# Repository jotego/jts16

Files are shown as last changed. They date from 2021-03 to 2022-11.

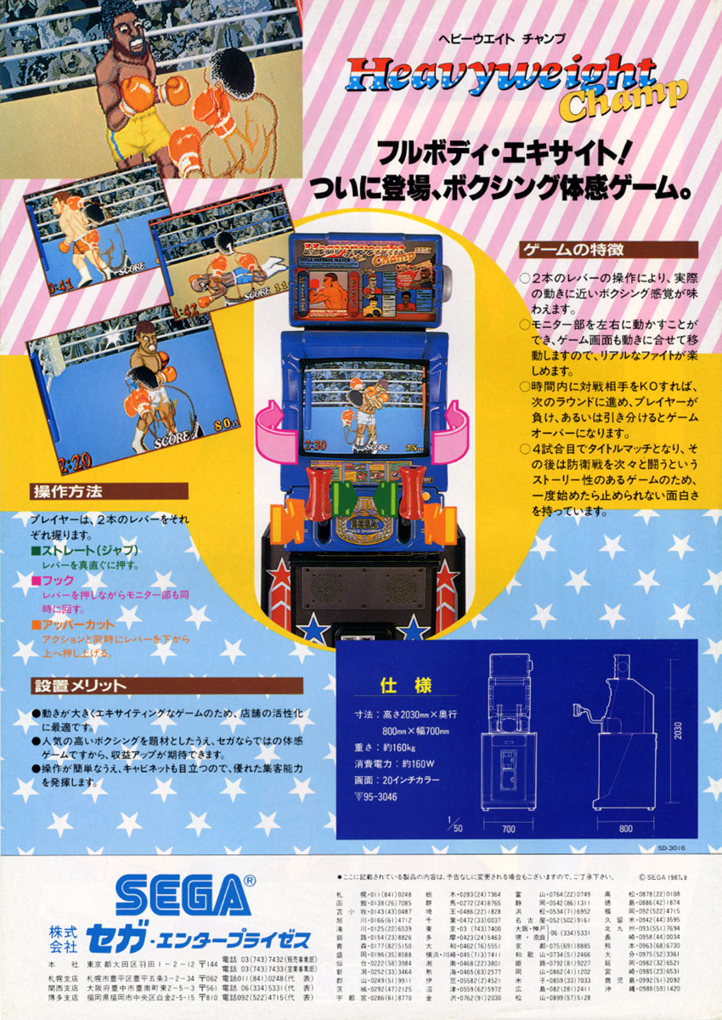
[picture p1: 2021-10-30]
doc/hwchamp controls.jpg

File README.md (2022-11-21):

# JTS16

You can show your appreciation through
* Patreon: https://patreon.com/jotego
* Paypal: https://paypal.me/topapate
* Github: https://github.com/sponsors/jotego

SEGA System 16 compatible verilog core for FPGA by Jose Tejada (jotego). This core was developed with the help of a SEGA System 16B model 171-5358 board lent by FunkyCochise and the Out Run board donated by Travis Brown.

This project aims to be compatible with System 16, Out Run and derivatives.

# Supported Games

Most games work correctly. Some games have problems mapping their inputs because the original arcade was not a joystick with buttons but something else hard to translate. Please check the [issues section in Github](https://github.com/jotego/jts16/issues).

Developer's note: encrypted games don't work if the core is compiled using the J68 CPU module for M68000.

# Special Inputs

Game           |  Players |  Analog    | Other
---------------|----------|------------|---------------
Passing Shot   |    4     |            |
SDI            |    1     |  2 axis    | trackball
Sukeban        |    1     |            | Keyboard-like
Major League   |    1     |  3 axis    |
Dump Matsumoto |    1     |            | inputs via 8751
Ace Attack     |    1     |            | inputs via CXD1095
Out Run        |    1     |  2 axis    |

# Core Division

Because of the hardware variety, there are different cores targeted for each of them

System               |  Core    | Logic Usage | BRAM Usage
---------------------|----------|-------------|-------------
16A                  | jts16    | 22,149      | 374,458
16B i8751            | jts16b   | 23,073      | 364,218
Super Hang-On        | jtshanon |             |
Out Run              | jtoutrun | 22,719      | 441,238

MiST has 608,256 memory bits and 24,624 logic elements.
Although the MCU can be synthesized in MiST and SiDi, timings are usually broken and requires several runs with different seeds because the FPGA is almost full. For MiSTer it seems to always go well.

The original Out Run design used a frame buffer to draw the sprites. The frame buffer is maintained for Pocket and MiSTer but it is not supported on some FPGA systems, like MiST. Because of the large number of sprites, it is not possible to process all sprite data in one scan line, so MiST and other systems some times have garbled lines as a result. This problem is minimized by doubling the video clock in those systems (up to 100MHz) but it still is visible in some scenes. Another side effect of missing the frame buffer is that sprites appear one-frame ahead of time in those systems.

Because of lack of sufficient internal FPGA RAM (called BRAM), MiST and other smaller systems cannot run the encrypted versions of these games.

Despite these problems, the MiST version is fully playable.

# PCB Check List

These items need double checking on the PCB

* How much shadow is created by sprite palette 3F? The core assumes 25% attenuation

# Clocks

HSync (OSSC) 15.73kHz
VSync (Analog Discovery) 60.042Hz
Vblank: 2.427 ms (38 lines)

Crystal Oscillators (System 16B)

Location | Freq (MHz) | Use
---------|------------|-------
B1       | 20         | M68k
E12      | 8.000      | Sound
G1       | 25.1748    | Video

Pixel clock: 6.2937 MHz

Estimated geometry:
    400 pixels/line = 63.555us = 15.734 kHz
    262 lines/frame

Core clock: 50.3496 MHz

Dividers:

Clock   |  m   |  n
--------|------|-----
25.1748 |   1  |   2
20      |  29  |  73
8       | 109  | 686

# 8255 Connections

Line   |  Destination
-------|--------------
PA     |  Sound latch
PB3-0  |  Coin lock ?
PB4    |  Display enable
PB6-5  |  ?
PB7    |  Flip (pull down)
PC7    |  Port A handshaking signal /OBF -> Sound /NMI
PC6    |  Port A handshaking signal ACK
PC5-3  |  Unconnected
PC2    |  To PAL 315-5107 pin 9 (SCONT1)
PC1    |  To PAL 315-5108 pin 19 (SCONT0)
PC0    |  To MUTE input on MB3733 amplifier (0=sound disabled)

# Memory Size

Item      |  Size (kB)
----------|------------
Main ROM  |  512
Main RAM  |   16
Object    |    2
Palette   |    4
Char      |    4
Scroll    |   32 (?)

# Support

You can show your appreciation through
* Patreon: https://patreon.com/jotego
* Paypal: https://paypal.me/topapate

# Licensing

Contact the author for special licensing needs. Otherwise follow the GPLv3 license attached.

# Patron Acknowledgement

Apart from the directors and supported shown in the core credits screen,
the following patrons also supported the development of JTS16:

```
0x157fae8              3style                 8bits4ever             Aaron Ray
Adam Leslie            Adam Rykowski          Adam Small             Adrian Labastida
Alan Shurvinton        Alda Alesio            Alec Peden             Alex Baldwin
Alex Mandic            Alexander Facchini     Alexander Lash         Alexander Upton
Alfonso Clemente       Allen Tipper           Allen Tulowitzki       Allister Fiend
Alvaro Paniagua        Andrea Chiavazza       Andreas Micklei        Andrew Boudreau
Andrew Hannan          Andrew P Gibson        Andrew Schmidt         Angel Aguinaga
Angelfred              Angelo Kanaris         AnotherJoe             Anselmo Moreno
Anthony Cheng          Anthony Monaco         Anton Gale             Arend Pronk
Arkadiusz              Arthur Fung            Aurich Lawson          BRCDEvg
Banane                 Barley Cheezers        Bear S                 Ben Cullen
Ben Tiefert            Ben Toman              BigRedPimp             Bit2018
Bitmap Bureau          Bitmaps Retro          Bliz 452               Boris Pruessmann
Brandon Lennie         Brandon Peach          Brandon Thomas         Brandoon
Brent Fraser           Brian Peek             Brian Shiver           Brianna Cluck
Bruce Fontaine         Bruno Meyere           Bruno Silva            Bryan Evans
Byshop303              Cameron Berkenpas      Cameron Tinker         Carlos Bailleres
Carlos Gruberman       Casey Hamann           Cedric Vioget          Cesar Sandoval
Chad Page              Charles                Chris                  Chris Angelini
Chris Babishoff        Chris D                Chris Davis            Chris Hauk
Chris Hoff             Chris Maguire          Chris Mzhickteno       Chris O'Neil
Chris Petroni          Chris Scully           Chris Sewell           Chris Tuckwell
Chris W Miller         Chris keesler          Chris smith            Christophe GARDES
Clayton Anderson       Clinton Cronin         Cobra Clips            Colin Colehour
Cory Sizemore          Cory Stargel           Cosmic Savant          Damien D
Daniel                 Daniel .               Daniel Dongil          Daniel Fowler
Daniel Page            Daniele Pellegrini     Danny Garfield         Darren Attwood
Darren Wootton         Daryll David           Dasutin                Dave Bennett
Dave Douglas           Dave Nice              David                  David Drury
David Fleetwood        David Jones            David Stone            Denis Brækhus
Dennis Ranker          Denny Letourneau       Devon Meunier          Diana Carolina
Didier Touron          Dimitris Zongas        Douglas Alves          Dr Catjail
Dr. Octagon            DrMnike                Dre137                 Dubesinhower
Ed                     Edward Mallett         Enthropy               Epixjava
Eren Kotan             Eric                   Eric Gutt              Eric J Faulkes
Eric Schneider         Eric Sorensen          F34R                   FROELIGER
Fabio Michelin         Fabrice Odero          Fabricio               Federico
Five Year Guy          Flavio Real            Florian Raoult         Franco Catrin
Fred Rojas             Gareth Jones           Gavin C                GeorgeSpinner
GigaBoots              Girth305               Glenn Percival         Gord Allott
Grant McNaught         Greg Sargent           Gregory Val            Grummkol
Guillermo Tunon        Gutxi Haitz            Guy Taylor             Gwaland
HamsoloPlays           Harmonica              Henry                  Henry R
Hentai Joe             Hugo Pinto             ItalianGrandma         ItsBobDudes
JR                     JSwan                  Jack Sammons           Jacob Hoffman
Jacob Lawter           Jakob Schmid           James Dingo            James Durden
James Mann             James Nivin            James Trautner         James Wilson
Janne Heikkarainen     Jason Baker            Javier Heredia         Jayson Larose
Jeremy Hopkins         Jerry Langwell         Jerry Suggs            Jerry Yuan
Jesse Clark            Jesse Rankin           Jim Knowler            Jimmy Richards
Jockel                 Joe Dinges             Joe Giuliano           Joel Albino
John Figueroa          John Fletcher          John Silva             John T. Keen
John Torn              John Wilson            John Woods             Johnny harvick
Jonah Phillips         Jonathan               Jonathan Tuttle        JonathanValls
Joost Peters           Jork Sonkinfield       Jose Perez             Josep Barbie
Joseph Kulinski        Joseph Milazzo         Joseph Mogavero        Josh Hogan
Josh Mayer             Josh Yates-Walker      Juan Barriga           Juan Pablo
Justin D'Arcangelo     Kai Cherry             Kai Luotojoki          Kaiosten
Kaya Bear              Keith Gordon           Kellerkind             Ken B
Ken Scott              Kevin Dayton           Kike Alcor             Kimberley Fisher
KnC                    Konrad                 Kricys                 Kristian.
KrzysFR                Kyle Pedersen          L.Rapter               Lakeside
Lee Grocott            Lee Osborne            Lucian                 Lucius Bono
Luis F Giron           M Reznor               MaDDoG                 Mack H
Madox                  Magnus Kvevlander      Mane Function          Manksalot
Manuel Astudillo       Marc Nuernberger       Marcello Medini        Mark Floyd
Mark Saunders          MarthSR                Matt Bouverie          Matt Evans
Matt Hargett           Matt Heinrich          Matt McCarthy          Matt Postema
Matt Simonds           Matt Vulcano           Matthew Compston       Matthew Woodford
Matthieu Marchione     Max                    Max Power              MechaGG
MiSTer Retro           Michael Anderson       Michael Bariszlovits   Michael Martin
Michael Rea            Michael_DKT            Mickaël Renou          Mike Holzinger
Mike Jegenjan          Mottzilla              Mysterious Benefactor  Nadir Shabazz
Nailbomb               Nando Iron             Nathan Souris          NerdyNester
Nicholas Bold          Nick Daniels           Nick Delia             Nick Gudauskas
Nico Stamp             Niko                   NonstopXiaowei         Noyman29
Obvious Fakename       Omar                   Omar Najera            OopsAllBerrys
Oriez                  Oskar Maria            Oskar Sigvardsson      Oyvind Christiansen
Pablo Avila-Estevez    Patrick McCarron       Patrick Roman          Paul
Paul Cunningham        Paulo M.               Paulo Nascimento       Paweł Mandes
PeFClic                Pedro Santiago         Per Ole                Peter Mehes
Philip Lai             Philip Lawson          Pierre-Emmanuel Martin Potato
ProfessorAnon          R Omar Leal            Rachel Schaeffer       Ralph Barbagallo
Ramon Gamaliel         RandomRetro            Raphael Melgar         Raul3D
RayGun                 RetroRGB               Retro_Brewz            Rex Kung
Rex Willer             Richard Eng            Richard Murillo        Richard Simpson
Robert Hayes           Robin Hertzberg        Romain Dijoux          Romier Silvera
Ronald Dean            Ronan Amicel           RoryDropkick           Ruben
Rune P                 Russ Crandall          Ryan                   Ryan Clark
Ryne Weiss             SIDKidd64              Saiyan                 Sam Hall
Samuel Pizarro         Samuel Warner          Sang Hee               Sascha Zupanek
Schnookums             Scott Bender           Ser Erris              Seth Wickline
Shad Uttam             Shannon King           Shen mue               Sherwood Hachtman
Sigmund68k             Skeletex               Spank Minister         Stadium ARTs
SteelRush              Stefan Krueger         Stephen                Stephen Pagenstecher
Stephen R Price        Steve Lin              Steve Skrzyniarz       Steve Tack
Steven A               Steven Hansen          Stoneman               Stuart Morton
Sunder Raj             SuperBabyHix           Synbios                TMoney
Taehyun Kim            Tales Dilli            Terse                  The Collector
The Video              Thomas Attanasio       Thorias                Tim Inman
Timothy Bearup         Tobias Dossin          Tom Milner             Tony Shong
Trifle                 Two Bards              Ty B                   Tyson Hanes
VickiViperZabel        Victor Bly             Victor Emmanuel        Victor Fontanez
Vincent Lietart        Wesley Lyons           Will Abbott            William Clemens
William Roussin        William Tryon          Xaxius                 Yunus Soğukkanlı
Zoltan Kovacs          aguijon                alejandro carlos       alexcom
amdrgn                 angel_killah           arcadebros             blackwine
brian burney           cbab                   chauviere benjamin     dARKrEIGn
dECKARD                datajerk               deathwombat            dzponce11
eclipse                eltee                  ill_deez               jbrlll
jim br                 jonathan capparelli    kccheng                kernelchagi
kerobaros              keropi                 liphy                  mattcurrie
mattyhochs             meijin3                metal                  myusernamewastaken
ogge_leander           ojwales                patrick woodburn       raoulvp
retroboi               rsn8887                slayer213              sourdille
thomas winfrey         tim rogers             tonitellezb            troy coberly
turbochop3300          twilitezoner           type78                 vampsthevampyre
yoaarond
```

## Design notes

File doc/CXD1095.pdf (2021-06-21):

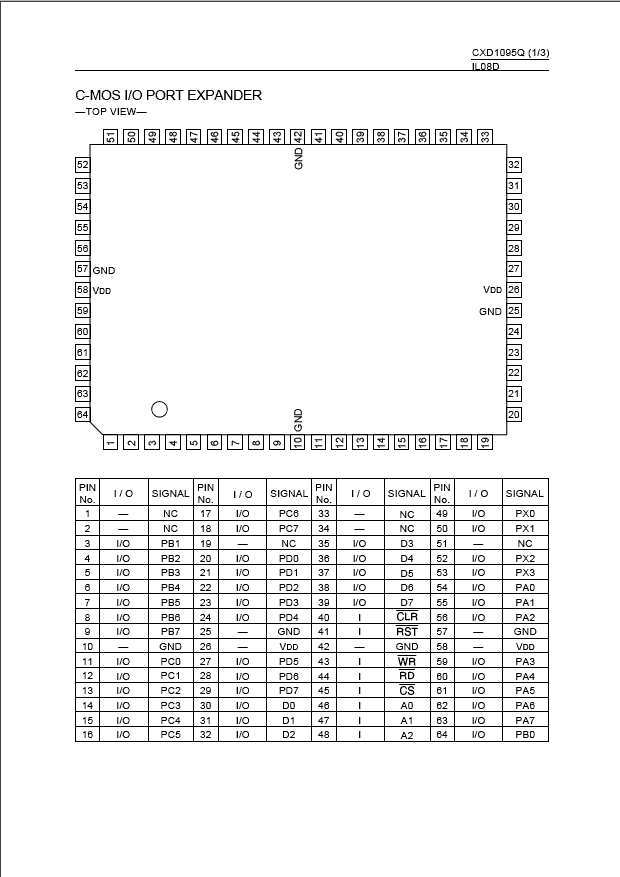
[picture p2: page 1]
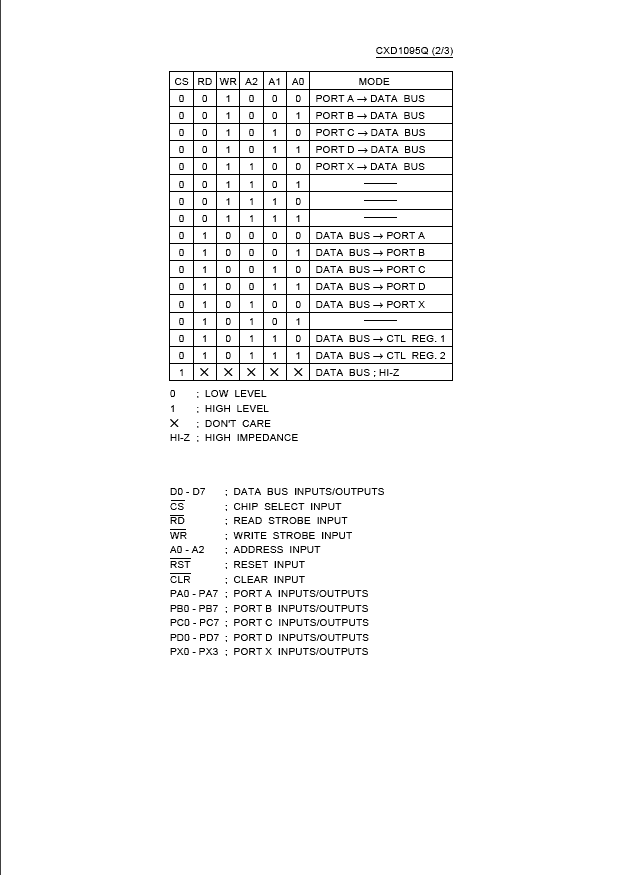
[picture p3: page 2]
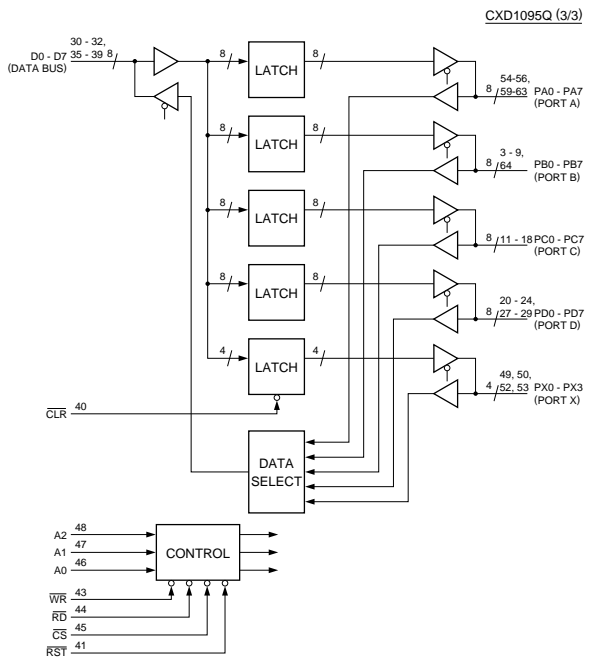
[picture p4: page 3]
LATCH; DATA SELECT; CONTROL; WR RD CS RST; CLR 40; D0 - D7 (DATA BUS; PA0 - PA7 (PORT A); PB0 - PB7 (PORT B); PC0 - PC7 (PORT C); PD0 - PD7 (PORT D); PX0 - PX3 (PORT X); CXD1095Q

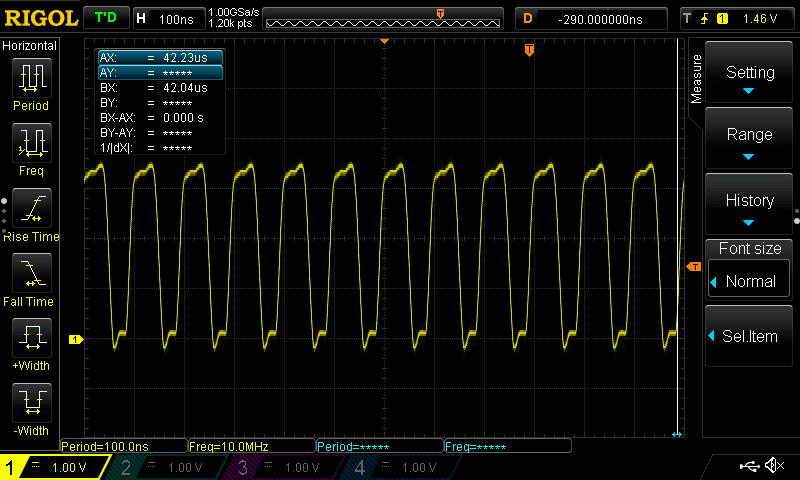
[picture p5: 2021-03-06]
doc/scope/M68000 clk.png

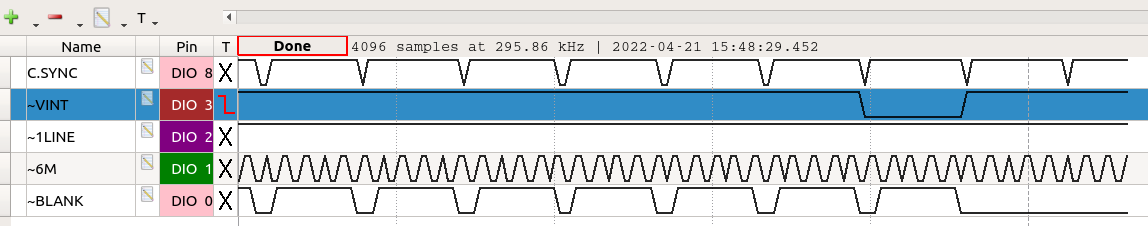
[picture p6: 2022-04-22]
doc/scope/S16_vint_timing.png

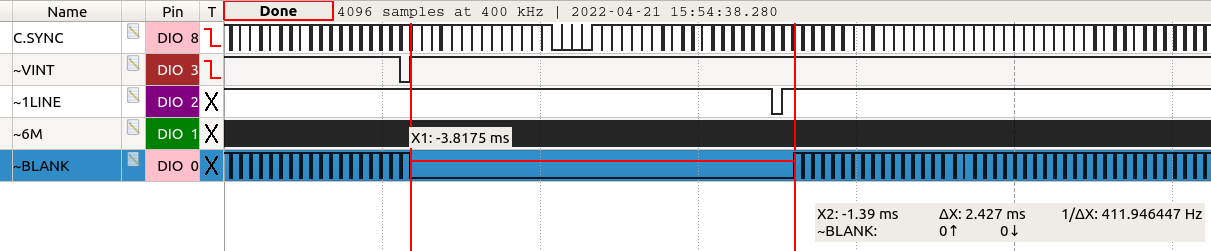
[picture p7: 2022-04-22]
doc/scope/S16_VBLANK.png

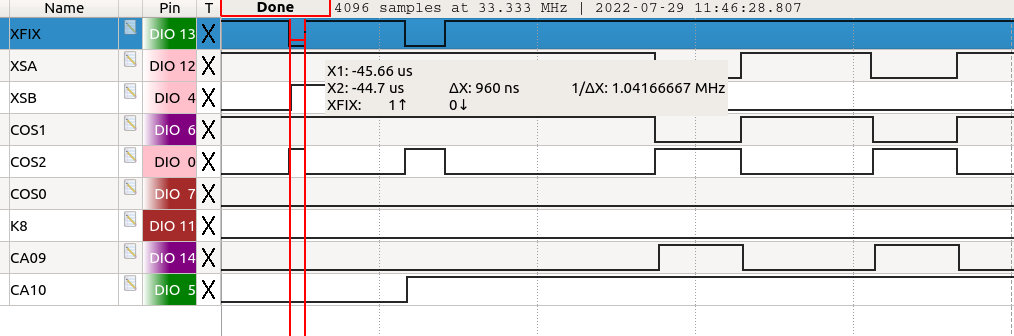
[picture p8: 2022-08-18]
doc/scope/wb3/wb3_-_2.png

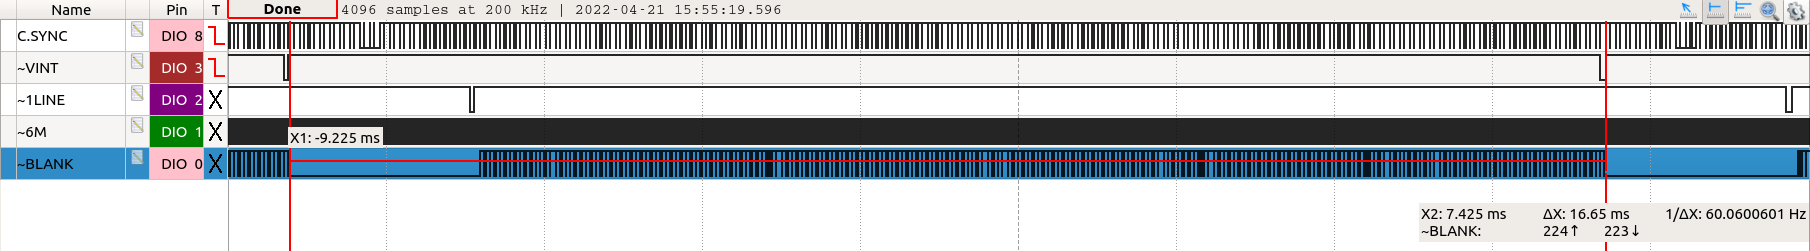
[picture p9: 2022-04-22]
doc/scope/S16_H_freq.png

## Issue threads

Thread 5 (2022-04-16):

[goldnaxe1] game locks in stage 2

jotego, 2022-04-16:
If the enemy is pushed off the cliff, the game doesn't let you advance. The go sign never shows up. Slashing the enemy lets you advance. Either killing method is ok in MAME.

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

Music gets corrupted too.

First seen in 7dc5bde

sqwirral, 2022-04-16:
`Golden Axe (set 1, World) (FD1094 317-0110)` - Crash (tested 2 times)
`Golden Axe (set 2, US) (8751 317-0112)` - No crash (tested 3 times)
`Golden Axe (set 3, World) (FD1094 317-0120)` - No crash (tested 1 time)
`Golden Axe (set 4, Japan) (FD1094 317-0121)` - No crash (tested 1 time)
`Golden Axe (set 5, US) (FD1094 317-0122)` - Crash (tested 1 time)

shuffle5, 2022-04-16:
i tried set 6 US version with ax battler, pushing off cliff with shoulder - no crash (2 times tested)

jotego, 2022-04-29:
It locks even with `git co 8072eb3 -- jtframe_68kdtack.v` on JTFRAME

jotego, 2022-07-06:
Retested in 29152a4 after the improved jtframe_68kdtack. It still happens.

jotego, 2022-07-15:
Fixed in 40b01df
The /IPL2 interrupt line was latched, but it shouldn't be

Closed 2022-07-15.

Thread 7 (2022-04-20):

261 lines/frame

paulb-nl, 2022-04-20:
Currently the core outputs 261 lines @ 60.28Hz.

I think it is more likely to be 262 lines @ 60.05Hz. This is 16.65ms per frame which is closer to the 16.64ms period shown in your IPL2 scope measurement.
https://github.com/jotego/jts16/blob/master/doc/scope/IPL2.png

jotego, 2022-04-21:
Indeed, 262 is the right number. I'll update the core. Thank you
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

jotego, 2022-04-22:
fixed in 1bee3db

Closed 2022-04-22.

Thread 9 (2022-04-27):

E-SWAT: glitch prevents advancement on stage 9

ryanfb, 2022-04-27:
Loaded up E-SWAT (set 4, World), playing through with default DIP switches, I noticed that once I got to stage 9 and advanced there's a sequence where enemies on trucks are supposed to appear, however, the first one glitches out, the rest don't appear, and you wind up stuck and unable to advance on a screen with no enemies.

Here's how the sequence is supposed to go from an arcade LP: https://youtu.be/1Bk04N-0ZLM?t=503

InsertDiskTwo, 2022-06-03:
I confirm this glitch.

jotego, 2022-07-15:
I thought it could be the same as #5 but tested it on commit 40b01df and the problem is still there.

RetroFonse, 2022-08-31:
This happened to me last night playing it on my MiSTer FPGA, i saved a clip of the glitch:
https://www.youtube.com/watch?v=yWaerfIBvb8

NewAstroCitys, 2022-09-19:
I also encountered the same issue earlier today.

NewAstroCitys, 2022-09-21:
In addition to my last post I have just tried the alternative core (Set 1, Japan FD1094 317-0131) and I did not encounter the glitch on stage 9.

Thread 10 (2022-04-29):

[ddux] Dynamite Dux color changes

jotego, 2022-04-29:
Checked on: c75b939 and c0c0fd9
It occurs, but if [git co 8072eb3 -- hdl/cpu/jtframe_68kdtack.v](https://github.com/jotego/jtframe/commit/8072eb3bc26d3d5caa720bd9f6e5b3d602404d24) for JTFRAME, it doesn't occur

jotego, 2022-07-06:
jtframe commits of jtframe_68kdtak.v that work with ddux
- 5a1f872 (may break Shinobi)
- 856447a
The first commit that breaks ddux is
- fec110a
But it fixes the Shinobi bonus stage

Closed 2022-07-06.

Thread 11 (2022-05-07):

Golden Axe slowdown

ArtemioUrbina, 2022-05-07:
Using Golden Axe set 4, Japan, FD1094 317-0121 (but happens on all versions) when compared to the Arcade PCB there are big slow down segments when several sprites are shown at once. It is very evident in the following video but happens almost everywhere.

[Video with issue](https://youtu.be/QvZaRKwWEbk?t=10)

Used my own ROMs from Japan set on the MiSTer FPGA. Both were running at teh same time and I tried to sync them as best as I could using two capture cards and both systems.

You can see the MiSTer Core slows down compared to the PCB. Core updated on May 7th 2022. PCB is running stock FD1094 317-0121 CPU.

Difference can be seen when pushing right on both the arcade PCB and Mister FPGA at the same time.

gyurco, 2022-05-13:
I confirm this, it starts to be noticeable in stage 2 (Turtle Village), when the dragons starts to appear.

ArtemioUrbina, 2022-08-06:
Confirmed

Closed 2022-07-06.

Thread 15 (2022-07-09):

Alien Syndrome

michelefornasini, 2022-07-09:
the audio samples are played all in a row at the start of the game, the sprite of the main character freezes

jotego, 2022-07-09:
Although this rings a bell, I think you must have tested an older version. Please use today's version jts16b_20220709 and jts16_20220709. I have not been able to reproduce any of these two problems in any of the seven Alien Syndrome variations.

Closed 2022-07-09.

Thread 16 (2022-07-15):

"Golden axe" & " Tough Turf" issues

kaloun34, 2022-07-15:
Hello
Since the update of 09/072022, the mra "Golden Axe" and "Tough Turf" switch to service mode at startup and it's impossible to leave it.
I managed it by forcing the service mode from the osd, but on reboot, same issue

jotego, 2022-07-15:
Please try deleting your old config files.

kaloun34, 2022-07-15:
I already tried it

jotego, 2022-07-16:
Thank you. I'll check it.

Videodr0me, 2022-07-17:
Same here. I think this can (also) be fixed by allowing to assign the "test button". This way one could just leave the "test program" and/or play around with it.

kaloun34, 2022-07-19:
It's the MRA that's the problem.
Issue with the MRA "Golden Axe (set 6, US) (8751 317-123A)"
No issue with the alternatives MRAs
 -  Golden Axe (set 4, Japan) (FD1094 317-0121)
 -  Golden Axe (set 5, US) (FD1094 317-0122)

asturur, 2022-09-19:
I want to add that the intro in goldenaxe has now broken graphic and sprites when the character are introduce.
The name is covered in white rectangles and the drawing seems off in colors.

(to leave the service mode, enter mister menu, press service mode on/off and you are out, that menu item serve as service button appartently)

NewAstroCitys, 2022-09-19:
> I want to add that the intro in goldenaxe has now broken graphic and sprites when the character are introduce.
> The name is covered in white rectangles and the drawing seems off in colors.
>
I have also experienced the same issue. Even though its not a game breaker it would be nice if this could be fixed.

shuffle5, 2022-09-25:
i get this too (service menu, plus the attract mode is corrupted where it shows the characters drawings. )
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

jotego, 2022-10-05:
verified in 7d64dbb
previous published version 21574e8 displays graphics correctly but it also starts in test mode. Versions earlier than that had the MCU version in a different RBF.
I think these are two different problems. I take the test-mode bug to issue #19

jotego, 2022-10-07:
Regression error introduced in ffb5179

```
 always @(posedge clk) if( pxl_cen ) begin
-    lyr0 <= tile_or_obj( obj_g[9:0], {4'd0, char_g[5:0] }, char_g[ 6], obj_prio==2'd3 );
-    lyr1 <= tile_or_obj( obj_g[9:0],        scr1_g[9:0]  , scr1_g[10], obj_prio>=2'd2 );
-    lyr2 <= tile_or_obj( obj_g[9:0],        scr2_g[9:0]  , scr2_g[10], obj_prio>=2'd1 );
-    lyr3 <= tile_or_obj( obj_g[9:0], {scr2_g[9:3], 3'd0 },       1'b0, 1'b1           );
+    lyr0 <= { 2'd0, tile_or_obj( obj_g[9:0], {4'd0, char_g[5:0] }, char_g[ 6], obj_prio==2'd3 ) };
+    lyr1 <= { 2'd1, tile_or_obj( obj_g[9:0],        scr1_g[9:0]  , scr1_g[10], obj_prio>=2'd2 ) };
+    lyr2 <= { 2'd2, tile_or_obj( obj_g[9:0],        scr2_g[9:0]  , scr2_g[10], obj_prio>=2'd1 ) };
+    lyr3 <= { 2'd2, tile_or_obj( obj_g[9:0], {scr2_g[9:3], 3'd0 },       1'b0, 1'b1           ) };
 end

 always @(*) begin
-    { shadow, pal_addr } =
+    { shadow, lyrsel, pal_addr } =
                (lyr0[10] ? lyr0[3:0]!=0 : lyr0[2:0]!=0) ? lyr0 : (
                (lyr1[10] ? lyr1[3:0]!=0 : lyr1[2:0]!=0) ? lyr1 : (
                (lyr2[10] ? lyr2[3:0]!=0 : lyr2[2:0]!=0) ? lyr2 : (
                 lyr3 )));
```
The shadow bit was incorrectly assigned because the newly layer-selection bits took the MSB part of the layer signals.

Fixed in d1ec409

Closed 2022-10-07.

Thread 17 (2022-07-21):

Out Run won't boot

jotego, 2022-07-21:
The memory tests pass, but the game won't boot. Once the game halts, it is possible to enter the test mode by pressing F2. Super Hang On boots, but the road is always a straight line and it doesn't get drawn.

- Tried separated access to SDRAM without bus handshaking between main and sub CPUs in be4a810. The memory tests still passed but the game didn't boot. Note that the road RAM doesn't seem to be accesses from the main CPU as it can be blocked in MAME and still works
- Tried disabling RECOVERY in jtframe_dtack
- Tried toggling the road RAM synchronously with the v-int (similar to the PCB) and asynchronously (like MAME)
- Tried not latching the input from the sub to the main CPU:
```
always @* begin
    bus_mux  = rom_cs  ? rom_data  :
               ram_cs  ? ram_data  :
               road_cs ? road_dout :
               16'hffff;
    sub_din = bus_mux;
end
```
- Tried fixed 1-clock DTACK delay in the mapper
- Tried giving 1 more bit to the main CPU RAM
```
always @(*) begin
    xram_addr = { ram_cs, main_addr[15:1] }; // RAM is mapped up
    //if( ram_cs ) xram_addr[15] = 0;
end
```
- Tried default settings for the ROM controller about the ok latch
```

    // Main CPU ROM
    .SLOT2_AW   (18),  // 512kB
    .SLOT2_DW   (16),
    //.SLOT2_OKLATCH( 0),

    // Sub CPU ROM
    .SLOT3_AW   (18),  // 512kB
    .SLOT3_DW   (16),
    //.SLOT3_OKLATCH( 1),
    .SLOT3_LATCH(0),
```
- Using a sdram_ok signal like in s16b
```
        if( ASn && BGACKn )
            sdram_ok <= 0;
        else if( !BUSn || !BGACKn ) begin
            sdram_ok <= rom_cs ? rom_ok : ram_ok;
        end
```

jotego, 2022-10-05:
Fixed in c40e13e

Closed 2022-10-05.

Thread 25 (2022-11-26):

shanon: band in the middle of the road

jotego, 2022-11-26:
commit: 831a6bc

There is a transparent band in the middle of the road. It looks like it should overlap with the road markings and not be transparent.

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

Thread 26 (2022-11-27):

[outrun] frame buffer

jotego, 2022-11-27:
Add frame buffer to sprites to match the 1-frame delay in the original board and to reduce MiSTer's clock to 50MHz. Work in progress in https://github.com/jotego/jtframe/tree/frame_buffer

jotego, 2022-11-28:
Both the MiSTer and the Pocket are not behaving as expected.

**MiSTer**

The DDR never seems to reply to the read and write commands. The busy signal seems dead. At one point, I saw activity when I changed the DDR base address. But I wasn't able to replicate it.

**Pocket**
The PSRAM does not toggle the wait pin.

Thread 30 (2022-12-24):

Embedded MCU code in the MRA

jotego, 2022-12-24:
### Problem
Users have trouble getting the zip file with the custom MCU firmware needed for games missing MCU dumps

### Action
Update the **mame2mra.toml** so assembler code is embedded in the MRA files.

### Tasks
- [x] https://github.com/jotego/jtframe/issues/94
- [x] Tough Turf
- [x] Wonder Boy 3
- [x] Publish update

Closed 2022-12-24.

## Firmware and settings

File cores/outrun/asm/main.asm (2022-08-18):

RAM     EQU $060000
SUB     EQU $200000
CHAR    EQU $110000
VRAM    EQU $100000

    ORG 0
    DC.L RAM+$8000
    DC.L RESET
    ORG $100

RESET:  
    ; Set the mapper values
    LEA.L $FFFFFF20,A0
    LEA.L MAPPER_LUT,A1
    MOVE.L #$F,D0
MAPPER_CFG:
    MOVE.W (A1)+,(A0)+
    DBRA D0,MAPPER_CFG

    ; copy the ROM
    MOVE.L #0,A0
    MOVE.L #RAM,A1
    MOVE.L #$8000>>2-1,D0
COPY_ROM:
    MOVE.L (A0)+,(A1)+
    DBF D0,COPY_ROM

    ; test the RAM vs ROM
    MOVE.L #0,A0
    MOVE.L #RAM,A1
    MOVE.L #$8000>>2-1,D0
    MOVE.L #1,D7
CMP_ROM:
    MOVE.L (A0)+,D1
    CMP.L (A1)+,D1
    BNE BAD
    DBF D0,CMP_ROM

    ; Copy the ROM to the CHAR space
    MOVE.L #0,A0
    MOVE.L #CHAR,A1
    MOVE.L #$1000>>2-1,D0   ; 4kB
COPY_ROM2CHAR:
    MOVE.L (A0)+,(A1)+
    DBF D0,COPY_ROM2CHAR

    ; Copy the ROM to the VRAM space
    MOVE.L #0,A0
    LEA.L  VRAM,A1
    MOVE.L #$1000>>2-1,D0   ; 4kB
COPY_ROM2VRAM:
    MOVE.L (A0)+,(A1)+
    DBF D0,COPY_ROM2VRAM

    ; Compare the CHAR and RAM copies
    LEA.L  CHAR,A0
    LEA.L  RAM,A1
    MOVE.L #$1000>>2-1,D0
    MOVE.L #2,D7
CMP_CHAR:
    MOVE.L (A0)+,D1
    CMP.L (A1)+,D1
    BNE BAD
    DBF D0,CMP_CHAR

    ; Compare the VRAM and RAM copies
    LEA.L  VRAM,A0
    LEA.L  RAM,A1
    MOVE.L #$1000>>2-1,D0
    MOVE.L #3,D7
CMP_VRAM:
    MOVE.L (A0)+,D1
    CMP.L (A1)+,D1
    BNE BAD
    DBF D0,CMP_VRAM

    ; Check the SUB CPU space
    ;;;;;;;;;;;;;;;;;;;;;;;;;;;;
    ; copy the sub CPU ROM
    LEA.L  SUB,A0
    LEA.L  SUB+$60000,A1
    MOVE.L #$8000>>2-1,D0
COPY_SUB:
    MOVE.L (A0)+,(A1)+
    DBF D0,COPY_SUB
    ; Test it
    LEA.L  SUB,A0
    LEA.L  SUB+$60000,A1
    MOVE.L #$8000>>2-1,D0
    MOVE.L #4,D7
TEST_SUB:
    MOVE.L (A0)+,D1
    CMP.L (A1)+,D1
    BNE BAD
    DBF D0,TEST_SUB

GOOD:
    MOVE.W #$BABE,D0
    MOVE.L #0,A0
    MOVE.W D0,(A0)
    BRA GOOD

BAD:
    MOVE.W #$BAD,D0
    MOVE.L #0,A0
    MOVE.W D0,(A0)+
    MOVE.W D7,(A0)
    BRA BAD

MAPPER_LUT:
    ;DS.W $0200, $0000, $0D00, $1000, $0000, $1200, $0C00, $1300
    ;DS.W $0800, $1400, $0F00, $2000, $0000, $0000, $0000, $0000

    DC.W $0002, $0000, $000D, $0010, $0000, $0012, $000C, $0013
    DC.W $0008, $0014, $000F, $0020, $0000, $0000, $0000, $0000
    DC.W $4A79, $0014, $0060, $4E4C, $4FF9, $0006, $7F00, $6100
    DC.W $0702, $6100, $0AC0, $6100, $5602, $4FF9, $0006, $7F00


;    ORG $0
;    DS.L SIO
;    DS.L RESET

    END

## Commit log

2021-03-06 More schematics
2021-03-10 Video timer
2021-03-14 Active frame length corrected to 224 lines
2021-03-18 Added filter, but it doesn't seem to filter
2021-03-19 Sets 60.3Hz refresh. Sound pop on MCU reset fixed
2021-03-28 Moved to real 8255, but the bonus stage bug remains
2021-03-28 Address decoder done like in MAME. Bonus stage issue remains
2021-03-28 Fixed size of OBJ RAM. Bonus stage bug remains
2021-04-25 Update Button String Configs / Add Quartet
    Adjusted button strings. Updated to 'quartet.xml' instead of 'quartet2a.xml' for additional versions for pre-system16. After running the script, you will receive the following errors due to the 'quartet.xml' housing all quartet roms "Quartet/Quartet 2". If you do not wish to support the four player version of Quartet, I understand. They are the same game just updated player counts from 4 to 2.
    quartet Quartet (Rev A, 8751 315-5194)
    ERROR: MAME defines a different button count (2) for game quartet (found 3)
    Button config string: Jump,Shot,-
    quarteta Quartet (8751 315-5194)
    ERROR: MAME defines a different button count (2) for g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
2021-05-30 Shinobi bonus stage bug goes away when using J68_CPU
2021-06-16 Attempt to fix Shinobi bonus stage
2021-06-16 Fixes Shinobi Bonus stage bug
2021-06-19 DIP switches moved to its own page in MiST
2021-06-22 Sample TOML file
2021-07-04 fixes Alien Syndrome buttons
2021-07-11 Device bits reordered
2021-07-13 MiST work flow
2021-07-21 Some buttons defined in TOML file
2021-07-26 PCB code added to MRA files
2021-09-15 Sound CPU interrupts the MCU via mapper
2021-09-17 8051 MCU gets synthesized wrong: interrupt polarity changes
2021-09-22 Starts the MCU 2 frames after the CPU, because Altered Beast programs the mapper at start
2021-10-20 JTFRAME: macro renamed BUTTONS->JTFRAME_BUTTONS
2021-11-03 Timer read ports fixed
2021-11-04 Fantasy Zone 2 DIP switches fixed
2021-11-06 S16A with MCU: wiring fixed - WIP
2021-11-12 Button names fixed
2021-11-12 The pause is done keeping vint low, to ease the single frame advance feature
2022-01-25 Removed previous bus value assignment for unmapped address. There are pull-ups in the schematics. This could affect Cotton according to MAME remarks
2022-04-20 Fixed commas in DIP switches
2022-07-15 line interrupt
2022-07-15 Line interrupt fixed
2022-07-15 IPL2 tracks vint pin, without latching it
2022-07-16 Remove decryption for non MiSTer devices
2022-07-18 Motor emulator
2022-07-18 Motor position bits
2022-07-18 Sub interrupt connected
2022-07-20 OutRun Controls
    1. Update TOML to reflect current mappings for OutRun
    2. Add controller_type toggle
    3. ADC Reads for dual analog stick, analog stick with analog triggers, analog wheel and digital inputs w/ buttons
2022-07-21 Turbo OutRun Inputs
    1. Separate low/high bits for digital inputs, fixes collision with B3/B4 on low/high bits
    2. Moves gear shift to button 3 and nitro to button 4
    3. Update TOML to reflect button mappings
    4. Generate new MRA files
2022-07-21 Super Hang On inputs - wheel reversed
2022-07-21 Accelerator ADC fix after cosmetic changes / Super Hang On Inputs
2022-07-23 Fixes voice A/13 Hi Tire in toutrun test menu
2022-10-30 - Moved to 96 MHz - Super Hang On uses its own core - Fixed road colors in SHANON - The road has a blank in the middle - The road may not be centered, especially in Out Run - Most MRA files related t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
2022-10-31 Objects better centered. Fixes transparent columns in stage 2 left. Fixes #12
2022-11-21 frame buffer - wip
2022-11-23 Some output produced in Out Run with line-based frame buffer
2022-11-24 first simulation with frame buffer that looks promising
2022-12-16 Added System 18 schematics
    [amd.kicad_sch, blanking.kicad_sch, capacitors.kicad_sch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]
2022-12-19 system 18 schematics transferred after update
    [amd.kicad_sch, blanking.kicad_sch, capacitors.kicad_sch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]
